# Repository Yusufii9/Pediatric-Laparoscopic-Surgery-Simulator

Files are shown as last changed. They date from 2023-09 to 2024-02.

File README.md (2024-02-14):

# Pediatric Laparoscopic Surgery Simulator

This repository for SYSC4907 Capstone Engineering Project "Pediatric Laparoscopic Surgery Simulator" at Carleton University (Fall 2023/Winter 2024)

## Project Details

- **Authors:** 
1. Atallah Madi
2. Esraa Alaa Aldeen
3. Huda Sheikh
4. Youssef Megahed
- **Date Created:** September 14, 2023
- **Last Edited:** February 14, 2024 

## Description

This project is a simulation software designed for pediatric laparoscopic surgery training. The code simulates various surgical tasks, such as ring and suturing tasks. It captures video input, processes the data, and provides real-time feedback based on sensor data. 

## How to Use

## Reqierments

To run the project, execute the `main.py` file. Different tasks and functionalities can be accessed through the GUI.

## Notes

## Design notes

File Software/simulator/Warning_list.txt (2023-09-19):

Warning Type and times (seconds): 
Force: 
Left Pitch Acceleration: 
Left Yaw Acceleration: 
Right Pitch Acceleration: 
Right Yaw Acceleration: 
Left Surge Acceleration: 
Left Roll Acceleration: 
Right Surge Acceleration: 
Right Roll Acceleration:

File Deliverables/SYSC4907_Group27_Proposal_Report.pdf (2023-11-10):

Capstone Project Proposal

# Pediatric Laparoscopic Surgery Simulator

## Augmented Reality Laparoscopic Surgery Training

Authors:

Atallah Madi | 101156350
Esraa Alaa Aldeen | 101151604
Huda Sheikh | 101144006
Youssef Megahed | 101133061

Group 27

(Biomedical and Electrical Engineering)

Supervised by:

Dr. Carlos Rossa

Report Date:
October 27th, 2023

SYSC 4907

Department of Systems and Computer Engineering

Faculty of Engineering and Design

Carleton University

Project Proposal | Group Number: 27

II

Table of Contents

III

Table of Figures

FIGURE 1 | 2
FIGURE 2 | 2
FIGURE 3 | 3
FIGURE 4 | 3
FIGURE 5 | 19
FIGURE 6 | 19
FIGURE 7 | 23
FIGURE 8 | 27

List of Tables

TABLE 1: | 26
TABLE 2: | 35

### 1. Introduction

This proposal outlines the research and development of the third iteration of the capstone

project that centers on developing a cutting-edge Pediatric Laparoscopic Surgery Simulator,

integrating augmented reality technology and machine learning to enhance its educational utility.

The following sections of this proposal commence with a concise articulation of the project's

primary objective, highlighting the need for innovative training tools in pediatric laparoscopic

surgery. Subsequently, a comprehensive background is constructed, encompassing the essence of

pediatric laparoscopic surgery, extant standards and requisites governing the domain of

laparoscopic surgical training, and a discerning analysis of recent advances in simulation

technology designed to augment the proficiency of laparoscopic surgeons. Furthermore, the

exploration of specific contributions and competencies of each team member, leveraging the

shared discipline of Biomedical and Electrical Engineering, as well as diverse practical

experiences, reinforces the team's collective capability to undertake this complex endeavour.

Moreover, a rigorous exposition of the planned methodologies is presented and supported by a

designed Grantt chart to track the project's milestones and timeline. An extensive risk assessment

and corresponding mitigation strategies are also delineated, followed by a listed inventory of

specialized components indispensable for the project's successful handover.

### 2. Background

Laparoscopic surgery, often called ‘keyhole’ surgery, is a minimally invasive surgical

(MIS) technique that differs from traditional ‘open surgery.’ Instead of making a large incision on

a patient’s abdomen, laparoscopy involves several smaller, 0.5-1 cm diameter incisions, each

called a ‘port’ [1]. A trocar placed inside a hollow sleeve or cannula at each incision or port is

slipped through to create an access point for surgery [2]. A trocar is a pen-shaped instrument

(triangular at one end) placed inside a hollow tubular instrument [2]. An image of a trocar is shown

below in Figure 1.

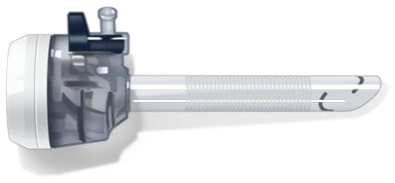
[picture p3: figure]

Figure 1 : Image of a trocar.[2]

In these incisions, the laparoscopic tools, a tube to pump gas into the abdominal cavity,

and a specialized camera called a laparoscope are placed through [3]. A sample placement of these

trocars is shown in Figure 2 below.

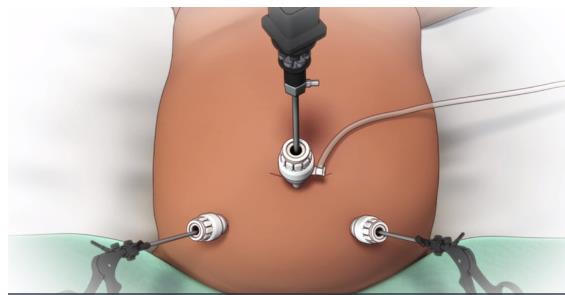
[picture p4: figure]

Figure 2: Pediatric laparoscopic surgery setup with a laparoscope and instruments inserted through trocars [3]

Various laparoscopic instruments available today are made of durable stainless-steel

material with narrow shafts up to 3-5mm diameter to fit through the ports [2]. Along with a

laparoscope, which is a thin telescope equipped with a camera and light source, there are a variety

of other tools available for various functions [2]. Needle drivers, composed of handles, joints, and

jaws, grasp suturing needles while securing wounds and surgical incisions [2]. Their tips may be

curved or straight [2]. Bowel graspers, 3 - 5 mm in diameter, handle and grasp tissue, allowing

surgeons to observe and perform various procedures [2]. Other instruments used in laparoscopy

include scissors, suturing needles, and surgical meshes [2]. An image of these tools is given in

Figure 3 below.

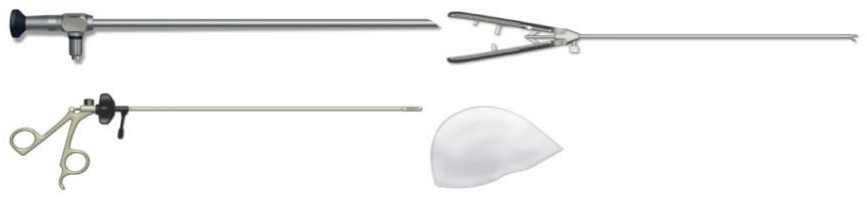
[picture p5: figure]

Figure 3: Laparoscopic instruments commonly used today. From left to right, laparoscope (top left), needle grasper

(top right), bowel grasper (bottom left), and surgical mesh (bottom right) [2]

Additionally, in laparoscopy, surgeons are limited to four degrees of freedom of motion,

which are the yaw, pitch, (counterclockwise/clockwise) roll, and (forward/backward) surge

movements [4]. They lose the heave and sway motions due to the pivots that hold the instruments

in place [4].

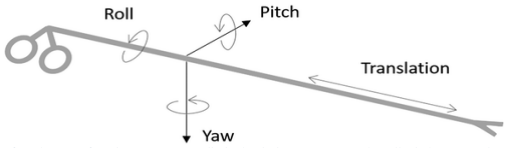
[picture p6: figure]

Figure 4:The four degrees of motion surgeons are limited to in laparoscopy are the roll, pitch, yaw, and surge

(translation) movements [4]

Regarding postoperative outcomes, due to smaller incisions, laparoscopy is associated with

reduced pain post-operation, reduced scarring, reduced hospital stays, and lower incidences of

significant wound complications [5]. That means patients can return to everyday life and engage

in normal activities much sooner after their operation than open-surgery patients [5].

However, laparoscopy is known to have a steeper learning curve for trainees than

conventional open surgery, and each patient-specific procedure can present additional

complications for surgeons and trainees [6]. Thus, training for laparoscopy is different from

conventional open surgery training in several ways. Trainees must work within restricted spaces

and exercise less intuitive and limited movement through the trocars [7]. They must also enhance

their hand-eye coordination capabilities due to the added challenges of operating while looking at

a screen instead of operating under direct vision, like in open surgery [7]. There is also an increased

need to develop manual dexterity skills, like fine motor skills, since the long instruments used in

laparoscopy amplify even small movements and errors made by the trainee [7]. Trainees also

experience the fulcrum effect, which describes the inversion of movement while operating [7]. For

instance, this refers to when the surgeon moves their hand to the right, and the instrument's tooltip

is moved to the patient's left on the screen [7].

Additionally, trainees have to grapple with challenges like only using four out of six

degrees of motion, the lack of physical sensation or touch from their hands, and the lack of 3-

dimensional images like in open surgery [7]. In a clinical setting, laparoscopic training can largely

depend on the variety of cases that arrive at the hospital [6]. Due to the increased need for the

unique skills required for laparoscopy, a need arose to develop relevant simulators and training

programs. Simulators provide trainees with a safe, ethical, and friendly learning environment to develop their hand-eye coordination abilities, improve their manual dexterity, and soften the

learning curve of acquiring laparoscopic skills [6].

When minimally invasive surgery (MIS) was first adapted for infants and children, training

surgeons and residents on pediatric laparoscopy presented additional challenges [8]. The use of

smaller workspaces, shorter and narrower instruments, smaller margins of error, and the expansion

of MIS in children and infants warranted the development of specific learning approaches and

simulators for pediatric laparoscopy [8]. This type of procedure demands a more unique set of

operating skills than adult laparoscopy. The abdomens of children and infants present a small

workspace whereby damage to nearby vessels, the bowel, and other structures can quickly occur

and lead to grave consequences [9]. While the instruments are smaller and narrower, surgeons

must still maneuver these within smaller anatomical structures and a restricted operating field

[9,10]. Due to these limitations, there also exists a lower tolerance of forces to surrounding tissues

[10]. Thus, the demand for the unique skill set to perform the procedure has led to the use and

development of pediatric laparoscopic simulators. These simulators must mimic the challenging

surgical environments in their setup by using smaller instruments, smaller needles, more sensitive

force-sensing devices, and more limited surface areas for training tasks [10].

The Fundamentals of Laparoscopic Surgery (FLS) was a program developed by the Society

of American Gastrointestinal and Endoscopic Surgeons (SAGES) in 2004 to develop a framework

that assesses knowledge and skills acquisition for laparoscopic surgery [11]. The program has been

widely regarded as a valid and reliable tool and educational curriculum to train and assess surgeons

[11]. The Canadian Association of General Surgeons endorses the FLS program as a valuable and

comprehensive training and assessment tool to gauge residents’ knowledge and skills in basic

laparoscopic training. The FLS examination consists of a web-based cognitive examination, followed by a manual-skills assessment on five fundamental laparoscopic tasks, namely, the peg

transfer task, precision cutting task, ligating loop task, suturing with extracorporeal knot-tying

task, and suturing with intracorporeal knot-tying task [11]. For now, and for our group’s proposed

surgical simulator, the focus will be on the peg transfer task and the suturing tasks with

extracorporeal knot-tying and intracorporeal knot-tying [11]. More tasks may be added to our

simulator if time, resources, and efforts allow.

The most straightforward task, the peg transfer task, involves using two Maryland grasper

dissectors [12]. It gets trainees to grasp each ring with their non-dominant hand one by one and

transfer it to their dominant hand in mid-air to place it on a peg on the opposite side of the board

[12]. The process is repeated until all rings are on the other side of the board [12]. This process is

then repeated in reverse, starting with the dominant hand and then transferring the rings to the non-

dominant hand [12]. Penalties are applied if the ring falls out of the field of view or is no longer

retrievable, but trainees are still expected to continue the procedure should this happen [12]. If a

ring is dropped within the field of view, trainees can pick it up with their hands and continue the

procedure [12]. The FLS recommends that trainees complete this entire procedure in 300 seconds,

with the time starting from the minute the grasper touches the first ring till the time the grasper lets

go of the last ring [12].

In the extracorporeal suturing task, trainees are expected to use two needle drivers (or one

Maryland grasper and one needle driver) and endoscopic scissors to place a long suture through

two marks in a Penrose drain and then perform three single throw knots (extracorporeally) to

secure the slit on the drain [12]. Then, once the three throws are secured, both ends of the suture

are cut [12]. Penalties are applied for a knot that falls apart, for deviating from the suturing marks

on the Penrose drain, and for improper closure of the slit [12]. This procedure is expected to be completed within 420 seconds, beginning when the first tool is visible through the camera and

ending when the cuts are made to either end of the suture [12].

Similarly, in the intracorporeal suturing task, trainees are expected to use two needle

drivers (or one Maryland grasper and one needle driver) and endoscopic scissors to place a short

suture through two marks in a Penrose drain and then perform three throws of a knot (one double

throw, and two single throws) intracorporeally to secure the slit on the drain [12]. Then, once the

three throws are secured, both ends of the suture are cut [12]. Penalties are applied for a knot that

falls apart, for deviating from the suturing marks on the Penrose drain, and for improper closure

of the slit [12]. This procedure is expected to be completed within 600 seconds, beginning when

the first tool is visible through the camera and ending when the cuts are made to both ends of the

suture [12]. While a scoring rubric from the FLS is not publicly available, plenty of scoring

methodologies developed by medical professionals exist online. They can be used to assess the

performance of trainees. For instance, many experts have developed independent scoring rubrics

for the five basic laparoscopic tasks [13].

To adapt the FLS training and assessment framework for pediatric laparoscopy, smaller

and softer rings for the peg transfer task, as well as the 3 mm graspers instead of the 5 mm ones

used for adult laparoscopy, should be employed [10]. The size of the Penrose drain used in the

intracorporeal, and extracorporeal suturing tasks should be reduced by 6, and smaller needles and

3 mm instruments should be used [10]. Additionally, the surface area of the Velcro securing the

drain to the board should be decreased by a factor of 5 to increase the risk of avulsion that can

occur due to the application of even minimal force in pediatric laparoscopy [10]. The timing and

penalty scores could be the same as that for adults, except additional parameters or penalties may need to be added to the scoring rubric for pediatric laparoscopies, such as assigning the trainee a

score of zero if avulsion of the Penrose drain occurs [10].

### 2.1. Description of Current Surgical Simulators

The advent of surgical simulators has opened a new avenue in surgical training. It provides

surgical residents and trainees with a safe, trainee-friendly learning environment to practice new

instruments, procedures, and skills before operating on actual patients [1]. Due to the rapidly

changing nature of instruments and laparoscopy’s less intuitive techniques/procedures, it is

difficult to use the traditional apprentice approach when teaching laparoscopic skills to novices

[1]. Thus, many surgical simulators have focused on developing simulation training for

laparoscopic surgery [1]. These have included low-tech and high-tech simulators like video-box

trainers, organic simulators (on human cadavers and animal models), hybrid trainers, virtual reality

(VR) trainers, and augmented reality (AR) simulators [14].

Video-box trainers resemble traditional box trainers in that they provide a box and holes

for trocar insertion and various laparoscopic tasks, but also a camera projected on a monitor for

the trainee [14]. While they can help practice hand-eye coordination skills and particular

laparoscopic tasks, they need more objective expert feedback and focus only on specific

tasks/techniques rather than an entire procedure [14]. They require the presence of an expert to

assess the performance of a trainee, which is only sometimes available. The FLS uses the McGill

Inanimate System for Training and Evaluation of Laparoscopic Skills (MISTELS) system to train

novices on the five core laparoscopic tasks as part of its laparoscopic training program [14].

Hybrid trainers, or virtual reality (VR) trainers, integrate video-box simulators with virtual

reality to guide a trainee throughout a performance with interactive haptic feedback and feedback

metrics without needing an expert surgeon to be present [14]. The user can practice individual skills like suturing, knot-tying, etc. or go through an entire procedure in a realistic computer-

generated environment in more advanced simulators [14]. Objective feedback can be in the form

of time taken for a particular procedure or the strength of a knot [14]. Several VR trainers for

different subspecialties have become available, including LapSim and Lapmentor simulators for

laparoscopy [14]. Sometimes, these simulators may require additional time and effort to set up and

maintain as they are not portable. However, they train residents to make sound decisions, preparing

them for intense operating environments [14].

Finally, augmented reality (AR) trainers, which overlay computer-generated information

into the user’s field of view, connect the virtual world to the real world [14]. Some of the

approaches covered by AR simulators include overlaying computer graphics on anatomical

structures, mapping instrument paths during a procedure, creating a realistic training environment

that involves real instruments interacting with actual artifacts in the surgical environment, and

providing objective force, motion, and haptic feedback without the need of an expert observing

the performance in real-time [14].

The current implementation of our Pediatric Laparoscopic Surgical Simulator project is an

augmented reality (AR) simulator, overlaying the surgical environment in the box trainer with

computer-generated information to guide the user through a laparoscopic task, like the peg transfer

task. Currently, thresholds from sensory information regarding force, velocity, and acceleration of

movement are used to assess trainee performance. Our current focus is to enhance the AR simulator

by adding more advanced laparoscopic tasks and integrating it with powerful machine

learning/data processing algorithms and an interactive user interface to enable it to recognize

surgical gestures and classify a user’s performance based on accurately collected expert data.

### 2.2. Machine Learning and Surgical Simulation

Current literature on laparoscopic surgical simulators has focused on applying artificial

intelligence (AI) to surgical simulators. AI aims to mimic human intelligence by learning to

predict, classify, and learn a particular task to make decisions [15]. AI can enhance surgical

simulators today by assessing a trainee's performance, providing more personalized feedback, and

enhancing the visualization of the surgical environment itself [15]. Among high costs and long-

term maintenance, current VR simulators like LapSim and AR simulators like ProMIS present

other limitations, like insufficient metrics/performance criteria to assess trainees [16]. For instance,

the ProMIS AR laparoscopic simulator uses "time of performance," "path length," and

"smoothness of motion" to assess trainee performance [16].

On the other hand, the LapSim simulator uses "time of performance," "tissue damage," and

"path length" to assess trainee performance [16]. "Time of performance" cannot be the most

important criterion with which to assess trainees, especially since the primary area of concern is

often whether the trainee has used the correct technique and tied a knot properly [16]. Most current

simulators do not accurately assess specific surgical techniques, compare a trainee's performance

to an expert's performance and provide constructive feedback that the user can understand or

implement [17]. Instead, they assume agreed-upon minimum threshold values for completion time,

path length, collisions, force, or velocity to assess a user's performance [17].

Machine learning can evaluate performance more accurately and provide more

personalized feedback to the user. For instance, machine learning algorithms can be trained to

recognize patterns of movement and behaviour in novice and expert performers to provide more

detailed feedback to the user. In this way, incorporating machine learning into our simulator will provide more instructional and informative feedback to the user, increasing the educational value

and usefulness of the simulator itself.

There have been several AI-related applications in surgical simulators in recent years [15].

A group at McGill University developed a machine learning algorithm that classified the skill

levels of surgeons during a brain tumour resection task and provided detailed feedback [15]. This

was done by getting machine learning algorithms to select important performance metrics from an

expert-defined list and use these to distinguish between the skill levels of surgeons in a virtual

reality simulator [15]. The algorithms could select a novel list of performance metrics and achieve

high classification accuracies when classifying trainee performances along training levels [15].

However, the challenges and problems introduced by applying AI and machine learning to surgical

simulation training must be addressed. For one, the lack of valid and objective performance metrics

for an algorithm to use, and another, the inability of the algorithm to accurately correlate between

a trainee's performance on a simulator and in the operating room [15]. In addition, these algorithms

may not consider the variety of methods and techniques trainees can use to achieve a particular

goal. Potential solutions to these problems could be to divide a procedure into sub-tasks and obtain

surgeon-led consensus on evaluation metrics in laparoscopy.

We aim to integrate our current AR pediatric laparoscopic surgical simulator with machine

learning algorithms to 1) classify individual gestures or sub-tasks within a surgical procedure (like

the peg transfer and suturing tasks) and 2) evaluate a trainee's performance and compare them to

an expert's performance. Our conversation with pediatric surgeons Dr. Ahmed Nasr and Dr.

Georges Azzie on September 27th, 2023, focused on how the machine learning algorithms that we

will develop can assess a trainee's success in completing each sub-task of a procedure by evaluating

their smoothness of movement, patterns of motion, and application of force. Each trainee's performance will be compared against the performances of actual, standard, expert data we have

collected. Our methodology regarding our machine learning approach is explained in Section 6,

our Methodology section.

### 3. Project Objective

The last iteration of the project focused on implementing a functioning box simulator

equipped with proper sensors to measure the characteristics of a surgeon’s hand movement and

force. The simulator was interfaced with augmented reality to provide simple but overly

mathematical feedback to the user through warnings and detailed graphs.

The primary goal of this capstone project is to develop a user-friendly training device for

pediatric laparoscopic surgery, integrating an embedded system for real-time guidance and

feedback. This iteration aims to reduce the reliance on expert surgical mentors, providing trainees

with a versatile and safe platform to improve their surgical skills independently while comparing

their performance to professional surgeons. Specific, measurable, functional, and non-functional

criteria will be employed to measure progress effectively. Functionally, the device's sensors must

accurately track intricate hand movements and measure applied forces on the training platform.

This multifaceted sensor system will facilitate real-time feedback through an augmented reality

interface to enhance the trainee's learning experience. However, the non-functional criteria will

cover factors related to the system's back and front end. The backend evaluates data pipelines,

signal processing, and machine learning model validation. The front end assesses the system

interface's responsiveness and robustness in delivering consistent feedback, including labelled

videos highlighting areas for improvement. A significant project objective is to enhance the

existing training setup by integrating new hardware components and then building efficient data

pipelines to process data from these integrated sensors and feed it to machine learning models.

Lastly, the project's final milestone includes presenting this data through augmented reality to

convey critical information and compare the trainee's performance to benchmarks supported by

machine learning models. This project signifies a commitment to advancing pediatric laparoscopic surgical training by combining technological innovation and education, creating a transformative

tool with significant potential to enhance surgical skills among trainees.

The design of this project will be executed in consultation with our supervisor, Dr. Carlos

Rossa, as well as pediatric surgeons from CHEO and the SickKids Hospital in Toronto, Dr. Ahmed

Nasr, and Dr. Georges Azzie.

### 4. Relevance to Degree Program

All members of the team - Atallah, Esraa, Huda, and Youssef - are currently in their final

year of their undergraduate degree program in Biomedical and Electrical Engineering. The degree

has equipped us with a shared foundational knowledge and skill set essential for our collaborative

effort. While each member brings unique strengths and expertise to the project, we all share a solid

academic background, ensuring that our overall project contributions will be closely aligned with

our studies and objectives.

Atallah’s academic journey has given him a deep understanding of concepts such as project

design, biomedical instrumentation, digital and analog electrical circuits, and various

programming languages. All these fundamental concepts come together to build his pivotal role in

the project, where he will focus on enhancing the platform design, upgrading its instrumentation,

and building the system data pipelines. His hardware, software, and electrical academic

background equip him with the skills essential to the project.

Esraa will utilize her academic knowledge to give her the essential skills and ability to

effectively contribute to gesture recognition of laparoscopic tasks. Her task will be accomplished

using deep learning or deep convolutional networks, which will extract robust features from real-

time data, and help provide several kinds of guidance according to the object states in training, to

enable easily understandable real-time feedback.

Huda, throughout her degree, alongside her course work, has worked on several projects

related to biomedical engineering in academics, research, and industry. Throughout these projects,

she has gained experience in image processing, biomedical imaging, sensor analysis, software

development, and project management. Huda’s primary role in this project will consist of

consolidating the machine learning aspects of the project (the performance assessment and gesture classification algorithms) with a powerful, interactive user interface (UI) that will guide and assess

a trainee throughout their performance. She will also ensure that the laparoscopic tasks added to

the project, such as the ring transfer and extracorporeal and intracorporeal suturing tasks, align

with the Fundamentals of Laparoscopic Surgery (FLS) requirements. This will ensure that the

laparoscopic surgical simulator functions correctly to give the user interactive feedback, as the

performance assessment and gesture classification algorithms provide.

Youssef's degree has afforded him comprehensive exposure to hardware/software

development, electrical engineering, and the intricacies of biomedical engineering. Beyond his

academic studies, Youssef has garnered hands-on experience in medical imaging research,

harnessing the power of deep learning. He has also honed his skills as a data science intern, adeptly

utilizing machine learning and Python. Youssef's combined expertise will be beneficial as he

works on developing the laparoscopic training simulator. His primary focus will be signal

processing and utilizing machine learning for classification purposes. Leveraging his deep-rooted

knowledge in biomedical engineering and data science, Youssef is poised to develop a robust

signal classification algorithm. This algorithm will adeptly process simulation data to assess

trainee performance accurately. Regarding signal processing, Youssef will adequately cleanse and

standardize raw sensor data, structuring it into data frames and saving them as CSV files. This

streamlined data will then be fed into the classification algorithm, offering insightful evaluations

of trainee performance. Youssef's diverse techniques and methodologies during his studies and

work serve as the foundation for his approach, promising users of the training simulator clarity

and precision in results.

### 5. Skills and Expertise

Our project is structured around four primary aspects: hardware development

improvements, signal processing and classification, gesture recognition, and user interface (UI)

enhancements. Drawing upon the engineering and design skills we have cultivated at Carleton

University, complemented by our co-op work experiences, our team is poised to execute these

tasks proficiently.

As a Digital Hardware Co-op with deep expertise in embedded systems, Atallah's

background plays a critical role in integrating new sensors. His skills in interfacing sensors with

microcontrollers ensure precise data collection. As an Undergraduate Research Assistant, he

excelled in optimizing data pipelines for complex CNN models in medical imaging. Atallah's skill

in constructing efficient data pipelines, refined through academic and professional experiences, is

vital for effectively managing data flow and processing. His proficiency in sensor integration,

platform instrumentation, and data pipeline optimization is pivotal for hardware improvements

with precision and excellence.

Esraa will leverage her grounding in biomedical and electrical engineering to harness the

power of deep learning. Her role involves extracting pivotal features from real-time data, a crucial

step toward achieving accurate gesture recognition. Gesture recognition will undoubtedly boost

the simulator's training efficacy.

Huda will combine her biomedical, electrical engineering, and software development

knowledge to create an interactive user interface (UI). Her vision also encompasses integrating

advanced laparoscopic tasks, such as the extracorporeal and intracorporeal suturing tasks, into the

simulator's existing setup.

With his biomedical and electrical engineering studies and a robust background in data

science and software development, Youssef will be responsible for signal processing. He will

further utilize Machine Learning algorithms for signal classification, aiming to enhance the trainee

experience by providing constructive feedback that can serve as a blueprint for performance

improvement.

With this diverse skill set, our team can handle individual responsibilities and provide

collaborative support when required. We are confident in our ability to deliver on the project's

expectations.

### 6. Methodology

### 6.1. Hardware Improvements

After conducting comprehensive testing and validating the project setup from the second

iteration, several key issues were identified within the overall design. These issues included

stability concerns, inaccuracies in readings, and inadequate housing for the sensors. Therefore, this

iteration's primary objective is to address these concerns by redesigning the current platform and

incorporating additional force sensors.

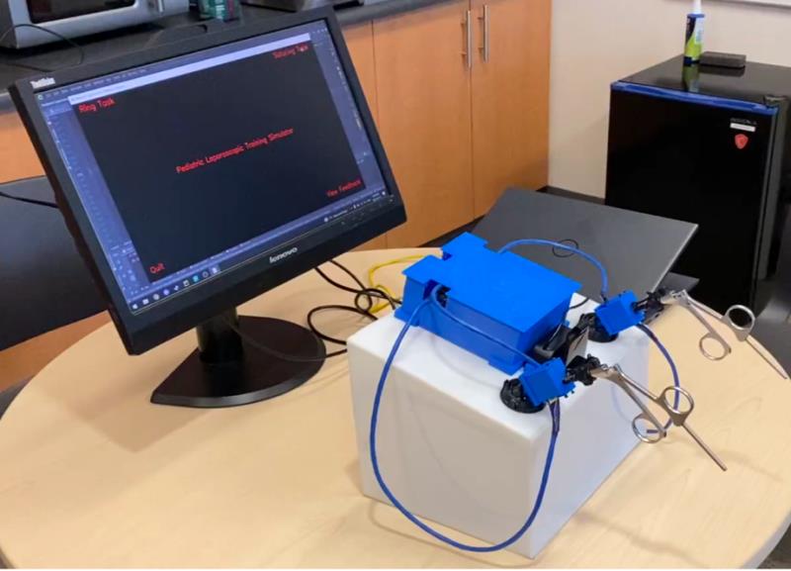
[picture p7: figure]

Figure 5: Current setup for the laparoscopic surgery trainer.

### 6.1.1. Force Sensors and Platform Redesign

For the force sensors, the current design allows the system to measure only the downward

applied force by placing FC22-31 0000 0100-L at the bottom of the platform, as shown in Figure

6.

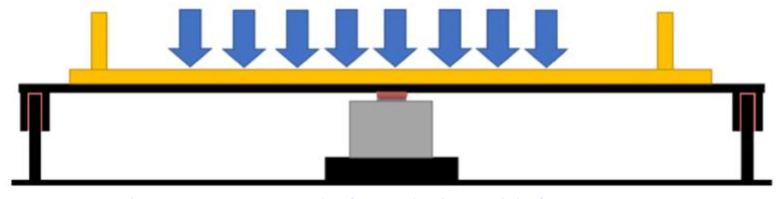
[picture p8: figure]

Figure 6: Current platform design with force sensor.

The sensor has a wide range of 0 to 100 ft-lb of force that can be detected [18]. The sensor

output is amplified by AD620 operational amplifiers to have an output ranging from 0 – 5V,

providing a higher resolution when converting the signal from analog to digital. A second force

sensor will be placed to improve the current accuracy of the downward force by averaging two

readings. Furthermore, two sensors will be added with an inverted configuration to collect upward

forces. This will highlight the forces applied in both directions, which in real-world applications

could damage and tear the patient’s tissues in surgery.

To strengthen platform stability, a comprehensive redesign has been undertaken using

Fusion 360 Computer-Aided Design (CAD) software. This redesign employs advanced CAD

techniques to refine the platform's structural integrity. The primary objective of this redesign is to

eliminate platform instability and reduce dependency on adhesives for stabilizing different

procedural platforms, which may cause damage when they are swapped. Additionally, within this

redesign, new space will be allocated for integrating new force sensors, improving the platform's

capacity to gather precise data and overall performance.

### 6.1.2. Embedded System

The existing microcontroller, Arduino Mega 2560 Rev 3, has been replaced with an

Arduino Nano Rev 3. This strategic transition was motivated by the imperative to maintain the

existing level of functionality while concurrently achieving a substantial reduction in the physical

footprint occupied by the microcontroller. This space will be occupied by a mounted screen and a

compact computer to achieve a truly portable design. The data pipelines are essential for feeding

data to the computer where the Python application runs to incorporate augmented reality

experiences. Therefore, fast serial communication between the microcontroller and the computer is much needed. This can be achieved using a fast serial communication protocol such as I2C

between the ends [19].

Clear and concise schematics are needed for a seamless hardware upgrade of the system.

This requirement can be met by using KiCad software to develop new schematics and incorporate

new components like force sensors and operational amplifiers. This simplifies the process and

makes building and working with intricate circuitry easier while maintaining the system's

functionality within spatial constraints.

### 6.2. Signal Processing and Classification

### 6.2.1. Sensor Data Collection and Initial Processing

During our simulator's most recent iteration, real-time data collected during simulations is

handled by an Arduino microcontroller on our end. The fundamental nature of the Arduino makes

it possible to acquire data from each sensor via the use of a signal controller in a seamless manner.

Therefore, this produces a complete dataset that includes parameters such as rotation, position,

speed, acceleration, and force. More classification is required to differentiate between the many

measures each metric represents.

Text files are used to store the raw data that is collected from the various sensors. Thus, a

Python script was developed that uses the 'tkinter' library so that the data processing can be done

more quickly. This script displays a dialogue window, which allows users to pick the appropriate

text file containing sensor data. After the selection, the data is cleaned, organized into a DataFrame,

and saved as a CSV file using the 'pandas' library. The visualization of data and its preparation for

classification algorithms may benefit from this automation's acceleration.

### 6.2.2. Enhancing Training Experience through Machine Learning

A pivotal aspect of this project is enhancing the trainee experience. In order to achieve this

goal, we are in the process of developing a machine-learning classification model. This model will

categorize trainee-generated signals into one of three proficiency levels: "Novice," "Intermediate,"

or "Expert." The classification is achieved by comparing the trainee's signal against a benchmark

'expert' signal, which is the model's training data.

Considering the input provided by the surgeons, we are emphasizing our feedback

mechanism. One strategy entails segmenting each task into smaller and more specific subtasks,

providing trainees with detailed insights into areas of improvement. For instance, the 'ring transfer'

task can be broken down into five distinct subtasks:

1. Retrieving the ring from the initial peg.
2. Maneuvering the ring to the task area's center.
3. Transferring the peg between graspers.
4. Relocating the ring to the designated peg.
5. Securing the ring onto the destination peg.

Given this segmentation, adopting a standardization approach from the 'sklearn' library is

imperative, ensuring uniformity in data points for each subtask across all trainees.

### 6.2.3. Dynamic Time Warping for Segment Matching

We will employ the Dynamic Time Warping (DTW) algorithm, available through the

'fastdtw' library, to identify and extract segments from trainee signals that align with expert signal

segments. The 'euclidean' distance metric from the 'scipy' library facilitates this comparison. DTW

stands out as a time-series similarity measure, adept at countering the effects of temporal shifts and distortions. It achieves this by enabling elastic adjustments to time series, ensuring the

detection of congruent shapes even if they manifest in differing phases [20].

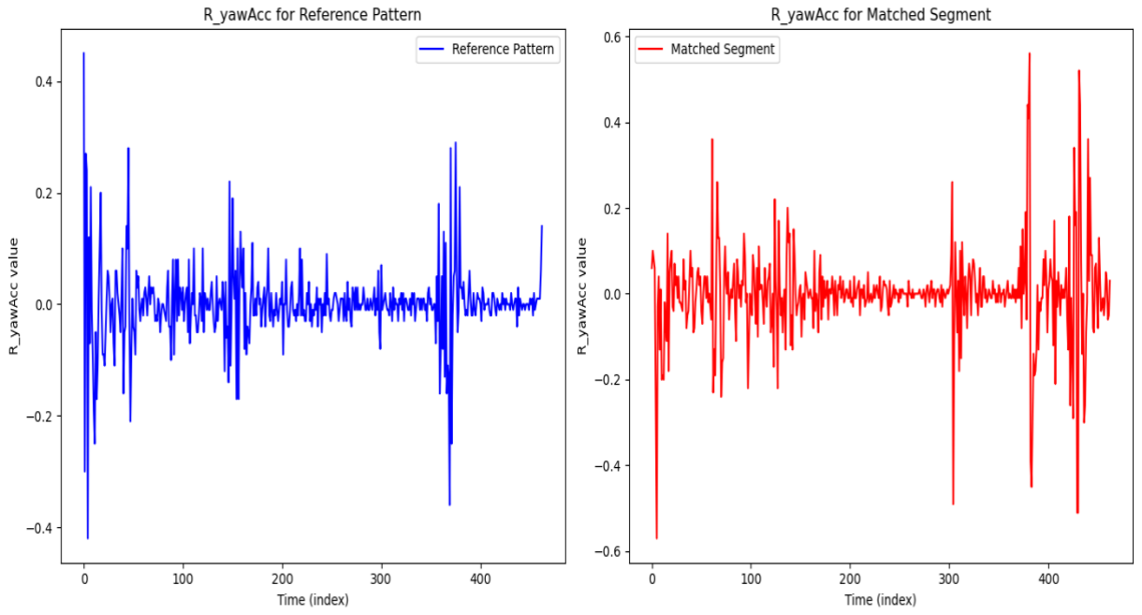
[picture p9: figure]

Figure 7: Comparative Analysis of ‘R_yawAcc’ signals: Reference Pattern vs. Matched Segment using DTW.

DTW's unique approach to time series comparison is essential in the context of our project.

It guarantees that trainee movements are recognized and evaluated accurately, as Figure 7 shows,

even if they are somewhat out of rhythm with expert maneuvers, delivering a fair and meaningful

assessment. By combining these aspects, the classification algorithm promises to be a robust tool

capable of providing informative feedback on trainees' performance and areas for potential

improvement.

### 6.3. Object Recognition

Many surgery complications are caused by inadequate individual team performance, for

which poor training and feedback play an essential role [21]. However, research indicates that half

of the adverse surgical circumstances are preventable. One improvement could be objective feedback through an object detection approach providing real-time automated surgical video

analysis. Hence, it is a way to evaluate the trainee's skills objectively and efficiently.

Deep learning-based approaches have two types: one-stage detectors and two-stage

detectors. In two-stage detectors, using deep features, the object detection method is applied to

locate and detect the developed semantic objects in an image [22]. Then, these components are

used for the classification and bounding box regression for the object candidate. Also, it will

achieve high detection accuracy [22].

On the other hand, bounding boxes are predicted over the images in one-stage detectors

without the region proposal step [22]. This process does not consume time and can be used in real-

time devices. Hence, for our design, our model's performance will rely on the object recognition

capability of the selected detection method and implementations of the different state-of-the-art

techniques that propose several efficient solutions and new directions as the plans to provide an

overview of how other deep learning models are used in generic object detection, specific object

detection, and object tracking [22].

Therefore, this task has two objectives: 1) The object modelling for the training task and

2) Object detection using deep learning to support real-time application of the simulator.

### 6.3.1. Object Modelling

Object modelling in machine learning refers to characterizing and describing objects to

allow machine learning algorithms to understand and work with them. Object modelling involves

determining a structured representation of objects, usually as attributes. The main objects for this

task are the left grasper, right grasper, and the ring states. The object model contains two

fundamental attributes for each target object:

- Location: to determine the exact pixel coordinates for the grasper.

- Movement: Our design considers movement a relationship between the objects and any

other object, such as holding the ring together with the left grasper, that indicates a

movement of “Ring transfer.”

Thus, each target object may have several object movements, as shown in Table 1, and

objects such as the ring and the grasper are required to know their movement. However, when

objects are represented in semantic modelling along with their semantic attributes and

relationships, machines can understand their meaning [23]

The semantic object model offers a method of representing objects in a task by combining

movement and object type attributes into a single attribute: location. The advantage of this

semantic object technique is the simplification of object state detection, as it will only detect the

location of the objects. This simplification can direct to efficient object detection methods.

Table 1: The Objects Classification by Movement and Location.

Gesture Index

(R: Right) and (L:

Left)

Objects Movement

Jaws (Open

or Closed)

RG0 | Ring on peg: Idle state (or hovering) | C
RG1 | Right grasper: Moving vertically downwards towards peg on right side of operating table | O/C
RG2 | Ring out peg: Positioning ring between the jaws and clasping it | O
RG3 | Right pick ring: Moving upwards with clasped ring | O
RG4 | Right Carry ring: Moving to center of operating table to meet left grasper | O
RG5 | Right carry ring: Hovering with ring between jaws for left grasper to pick | O
RG6 | Ring transfer: Holding ring together with left grasper | O
RG7 | Right pick ring: Opening jaws to let go of ring | O
RG8 | Moving aside | O/C
LG0 | Idle state (or hovering) | C
LG1 | Left grasper: Moving to center of operating table to meet right grasper | O/C
LG2 | Left pick ring: Positioning ring between the jaws | O
LG3 | Left pick ring: Clasping ring | O
LG4 | Left carry ring: Moving horizontally (straight or diagonally) towards a peg on left side of operating table | O
LG5 | Left carry ring: Positioning ring over peg | O
LG6 | Ring on peg: Opening jaws and dropping ring through peg | O/C
LG7 | Ring on peg: Moving aside after transferring all three rings | O/C

### 6.3.2. Object detection using deep learning: Single Shot Detection

A single-shot detector is a one-phase detector that predicts multiple classes. In other words,

a real-time object detection framework that merges the tasks of object localization and type into a

single unified architecture [24]. In this task, after modelling the semantic objects. The primary plan

concept is Multiscale Bounding Box Prediction and the training.

### 6.3.2.1. Multiscale Bounding Box Prediction

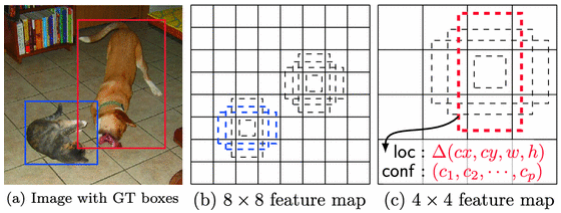
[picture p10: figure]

Figure 8: The figure shows SSD framework (a) Image with GT box. (b) 8×8 feature map. (c) 4×4 feature map.[24]

The SSD approach's target output is to predict an object's presence on different scales. This

multiscale technique allows SSD to detect objects of various dimensions and positions in the input

image. The approach is as follows:

- Input Image and Ground Truth: The SSD only needs an input image with objects to be

detected. The object in the image is associated with a ground truth box for each object

during training, as shown in Figure 8 (a) [24].

- Convolutional Neural Network (CNN): using CNN to detect objects of different sizes and

forms, these boxes are considered at multiple positions on different feature maps of various

resolutions (as shown in Figures 8 b and c: 8x8 and 4x4).

- Multiple Fixed Scale Grid Feature Maps: generates multiple fixed-scale grid feature maps

and captures segments at various spatial resolutions within the image shown in Figure 8(b)

and (c).

- Default Boxes: A collection of default boxes is connected per location on the feature maps

and operates as reference templates for object detection.

- Multiscale Bounding Box Prediction: aims to predict objects' existence at multiple scales.
- Final Feature Map: All the feature maps from other scales are compiled into a final feature

map containing the predictions for shape offsets, classification scores and attributes for

each default box.

### 6.3.2.2. Training

Dataset Preparation: A training dataset is prepared that contains labelled images. Each

image should have ground truth information that needs to be assigned to specific outputs in the

fixed set of detector outputs [24].

- The loss function and backpropagation: The loss function generally has object localization

and classification components. Represent a loss function quantifying the discrepancy

between the model's predictions and the ground truth information.

- Default Box Selection
- Ground Truth Label Conversion: The ground truth information for the training images is

converted to correspond to the output format expected by the SSD model.

- Dataset Augmentation: Each training image is randomly sampled to construct a better and

more robust model with different input object dimensions and shapes [24].

- Training Iterations: In each iteration, the model processes small batches of images and

updates its parameters using a matching optimization algorithm.

- Validation and Thresholding: A threshold is used to select which object detections are

proper based on confidence scores. Detections with scores beyond the threshold are

retained.

### 6.4. User Interface Design

The design of the user interface will be implemented using Python’s tkinter package, which

is a standard interface for a GUI toolkit [25]. This package provides an efficient way for us to

implement buttons, display screens, menus, and images that will guide the trainee throughout the

execution of their training program. This user interface will be implemented through object-

oriented programming, a programming paradigm that defines classes of independent objects with

inherited methods and variables but their states [26]. This will allow for code reusability,

efficiency, and extensibility and is usually the default programming paradigm for a program of

this type and scale.

### 6.5. Laparoscopic Training Tasks

This project will implement the peg transfer task and the intracorporeal and extracorporeal

tasks from the FLS program. While the current implementation of the peg transfer task is set up

with three pegs on either side of the board and three rings to transfer, the suturing task has yet to

be formally set up in the previous implementation of this project. A durable silicone suturing pad

will be sealed to the platform of the box simulator. Materials needed for the suturing task will be

2/0, 3/0 or 4/0 curved suturing needles of the longest available size, like 25 mm or 17 mm needles

(for ease of visibility through a camera), as well as two needle drivers, and one pair of endoscopic

scissors to perform the task.

### 7. Project Timetable

A Gantt chart is a project management tool visually representing a project's timeline and

objectives. It displays tasks on the vertical axis and time on the horizontal axis, enabling team

members to visualize the project's progression and discern the interrelation between various

subtasks.

Every member has described their responsibilities for the 2023-2024 year and estimated

the duration required to complete their tasks. Also, we have set collaborative milestones, such as

the final project deliverable, based on contributions from all the team members. Everyone must

dedicate at least 8 hours weekly to the project throughout the year. The Gantt chart detailing this

can be found attached in Appendix A.

### 8. Risk Assessment and Mitigation

Considering potential risks and developing mitigation plans is crucial for effective project

management. This approach helps the project team to be prepared for uncertainties and enhances

the possibilities of project success. Identifying potential issues that could occur during the project

is a crucial initial step, such as the change from the Arduino Mega 2560 Rev 3 to the Arduino

Nano Rev 3. This change carries potential risks, specifically regarding software compatibility and

unexpected hardware adaptation challenges. However, a well-defined plan has been set to manage

these circumstances, including comprehensive testing and validation procedures to ensure a

smooth transition, thereby reducing the risk of functional disruptions. Other team members have

also implemented and thoroughly reviewed a detailed schematic model to minimize errors and

ensure the seamless integration of new components. These measures are created to mitigate

potential risks to the project timeline and ensure these critical hardware advancements are

successfully implemented.

Instability during the training box platform assessment was observed and identified several

risks. A platform redesign using Fusion 360 (CAD) software was proposed to address this issue.

However, due to potential design compatibility problems, new structural changes and force sensors

could result in unexpected issues. To mitigate these risks, the supervisor will conduct design

reviews and implement trial-and-error plans to ensure the seamless integration and compatibility

of the changes.

Furthermore, storing project information and data is essential to ensure the project's

continuity and success. We use cloud services, such as OneDrive for files and documentation,

GitHub for software, and Fusion 360 for design backups, to mitigate the risk of data or information

loss. However, despite the reliability of these cloud services, there is always a potential risk of data loss. To address this, we will schedule regular backups to ensure redundant storage across multiple

locations. Also, automated backup and version control systems will be implemented to minimize

the risk of data loss.

### 9. Special Components and Facilities

As we begin the third iteration of our project, we will use a wide range of specialized tools

and components.

1. 3D Modeling & Printing:
- Modelling Software: We will utilize AutoDesk Fusion 360 for 3D modeling.
- 3D Printer: The DREMEL from Digilab, located in the Biomechatronic lab, will print our

designs.

- PLA Filament: Used for 3D printing components, it emulates the physical environment of

a pediatric abdomen during laparoscopy.

2. Sensor Communication & Control
- Microcontroller: The Arduino Nano Rev 3 will interface with the PMW 3389, MPU 6050,

and FC2211-0000-0025-L sensors

- Development Environment: The open-source Arduino IDE ensures seamless sensor

communication.

3. Software Development & Data Processing
- Python Language: A versatile choice for augmented reality, signal processing,

classification algorithms, and gesture recognition. It is also compatible with the Arduino

Nano Rev 3 for serial data communication and supports machine and deep learning

applications.

4. Simulator Design & Components
- AutoCAD: Precision design software for crafting the platform housing diverse laparoscopy

tasks.

- Force Sensors (FC2211-0000-0025-L): Vital for tactile feedback simulation during

laparoscopic procedures, aiding trainees in honing their touch and dexterity.

- Operational Amplifiers (AD620): Four amplifiers will condition and amplify signals from

the force sensors.

- Suturing Equipment: A suturing pad and 26mm needles enable realistic suturing technique

practice.

- PWM 3389 and MPU-6050: Essential for the four degrees of movements
5. Components depend on the approval of additional funding.
- Mini PC: This acts as the simulator's computing heart, orchestrating software simulations,

performance metric recording, and trainee feedback.

- LED Matrix: The matrix gives a realistic representation of the surgical field, while the

wires cater to circuitry needs.

- Display & Feedback System: An IPS display, and FOV web camera collectively create an

immersive training interface.

With this comprehensive suite, we are poised to deliver a simulator that offers trainees a holistic,

realistic, and educative experience.

### 10. Report Contributions

Table 2: Outline of each member's contribution to the proposal report

Contributor | Section
Atallah Madi | • Introduction • Project Objective • Relevance to Degree Program • Methodology (Hardware Improvements)
Esraa Alaa Aldeen | • Relevance to Degree Program • Methodology (Object Recognition) • Project Timetable • Risk Assessment and Mitigation
Huda Sheikh | • Background • Relevance to Degree Program • Methodology (User Interface and Design Laparoscopic Training Tasks)
Youssef Megahed | • Relevance to Degree Program • Skills and Expertise • Methodology (Signal Processing and Classification) • Special Components and Facilities

References

[1] “Laparoscopic Surgery - What is it? | ASCRS,” fascrs.org.

https://fascrs.org/patients/diseases-and-conditions/a-z/laparoscopic-surgery-what-is-it

[2] “What Tools are Used in Laparoscopic Surgery | Laparoscopic.MD,”

https://www.laparoscopic.md/surgery/instruments#:~:text=Laparoscopic%20instruments

%20are%20made%20of (accessed Oct. 14, 2023).

[3] “Laparoscopy in Children,” myhealth.alberta.ca.

https://myhealth.alberta.ca/health/Pages/conditions.aspx?hwid=acg9455 (accessed Oct.

14, 2023).

[4] Bojan Gavrilović, A. S. Fahy, B. Carrillo, A. Nasr, J. Ted Gerstle, and Georges Azzie,

“Development of an Open-Source Laparoscopic Simulator Capable of Motion and Force

Assessment: High Tech at Low Cost,” Journal of Laparoendoscopic & Advanced

Surgical Techniques, vol. 28, no. 10, pp. 1253–1260, Oct. 2018, doi:

https://doi.org/10.1089/lap.2018.0126.

[5] P. K. H. Tam, “Current topic: Laparoscopic surgery in children,” Archives of Disease in

Childhood, vol. 82, no. 3, pp. 240–243, Mar. 2000, doi:

https://doi.org/10.1136/adc.82.3.240.

[6] E. Westwood, B. Malla, J. Ward, R. Lal, and K. Aryal, “The Impact of a Laparoscopic

Surgery Training Course in a Developing Country,” World Journal of Surgery, vol. 44,

no. 10, pp. 3284–3289, Jun. 2020, doi: https://doi.org/10.1007/s00268-020-05606-y.

[7] M. Nagendran, C. D. Toon, B. R. Davidson, and K. S. Gurusamy, “Laparoscopic surgical box

model training for surgical trainees with no prior laparoscopic experience,” Cochrane

Database of Systematic Reviews, Jan. 2014, doi:

https://doi.org/10.1002/14651858.cd010479.pub2.

[8] Y. A. Oquendo, E. W. Riddle, D. Hiller, T. A. Blinman, and K. J. Kuchenbecker,

“Automatically rating trainee skill at a pediatric laparoscopic suturing task,” Surgical

Endoscopy, vol. 32, no. 4, pp. 1840–1857, Oct. 2017, doi:

https://doi.org/10.1007/s00464-017-5873-6.

[9] P. Korzeniowski, C. S. Chacon, V. R. Russell, S. A. Clarke, and F. Bello, “Virtual Reality

Simulator for Pediatric Laparoscopic Inguinal Hernia Repair,” Journal of

Laparoendoscopic & Advanced Surgical Techniques, vol. 31, no. 11, pp. 1322–1330,

Nov. 2021, doi: https://doi.org/10.1089/lap.2020.0423.

[10] G. Azzie et al., “Development and validation of a pediatric laparoscopic surgery simulator,”

Journal of Pediatric Surgery, vol. 46, no. 5, pp. 897–903, May 2011, doi:

https://doi.org/10.1016/j.jpedsurg.2011.02.026.

[11] H.-C. Hur, D. Arden, L. E. Dodge, B. Zheng, and H. A. Ricciotti, “Fundamentals of

Laparoscopic Surgery: A Surgical Skills Assessment Tool in Gynecology,” vol. 15, no. 1,

pp. 21–26, Jan. 2011, doi: https://doi.org/10.4293/108680810x12924466009122.

[12] “FLS Manual Skills Written Instructions and Performance Guidelines Important Scoring

Information.” Accessed: Aug. 26, 2022. [Online]. Available:

https://www.flsprogram.org/wp-content/uploads/2014/03/Revised-Manual-Skills-

Guidelines-February-2014.pdf

[13] S. Miles and N. Donnellan, “Learning Fundamentals of Laparoscopic Surgery Manual

Skills: An Institutional Experience With Remote Coaching and Assessment,” Military

Medicine, Apr. 2021, doi: https://doi.org/10.1093/milmed/usab170.

[14] M. Varras, N. Nikiteas, V. Varra, F. Varra, E. Georgiou, and C. Loukas, “Role of

laparoscopic simulators in the development and assessment of laparoscopic surgical skills

in laparoscopic surgery and gynecology (Review),” World Academy of Sciences Journal,

Mar. 2020, doi: https://doi.org/10.3892/wasj.2020.41.

[15] J. J. Park, J. Tiefenbach, and A. K. Demetriades, “The role of artificial intelligence in

surgical simulation,” vol. 4, Dec. 2022, doi: https://doi.org/10.3389/fmedt.2022.1076755.

[16] S. M. B. I. Botden, S. N. Buzink, M. P. Schijven, and J. J. Jakimowicz, “Augmented versus

Virtual Reality Laparoscopic Simulation: What Is the Difference?,” World Journal of

Surgery, vol. 31, no. 4, pp. 764–772, Mar. 2007, doi: https://doi.org/10.1007/s00268-006-

0724-y.

[17] C. Sewell et al., “Providing metrics and performance feedback in a surgical simulator,”

Computer Aided Surgery, vol. 13, no. 2, pp. 63–81, Jan. 2008, doi:

https://doi.org/10.3109/10929080801957712.

[18] “Compression Load Cell - 100mV / 0.5-4.5V | FC22 Series,” Compression Load Cell -
100mV / 0.5-4.5V | FC22 Series. https://www.te.com/usa-en/product-CAT-FSE0001.html

(accessed Oct. 18, 2023).

[19] Arduino, “Arduino Nano,” Arduino Official Store. https://store.arduino.cc/products/arduino-

nano

[20] P. Senin, “Dynamic time warping algorithm review.” Information and Computer Science

Department University of Hawaii at Manoa Honolulu, USA, 855(1-23), 40, December

2008. [Accessed Oct. 7, 2023]. Available: https://www.researchgate.net/profile/Pavel-

Senin/publication/228785661_Dynamic_Time_Warping_Algorithm_Review/links/02bfe

5100f11a7929f000000/Dynamic-Time-Warping-Algorithm-Review.pdf.

[21] Gawande AA, Thomas EJ, Zinner MJ, Brennan TA. The incidence and nature of surgical

adverse events in Colorado and Utah in 1992. Surgery. 1999 Jul;126(1):66-75. doi:

10.1067/msy.1999.98664. PMID: 10418594.

[22] Pal, S.K., Pramanik, A., Maiti, J. et al. Deep learning in multi-object detection and tracking:

state of the art. Appl Intell 51, 6400–6429 (2021). https://doi.org/10.1007/s10489-021-

02293-7

[23] Brachman, R. J., & Levesque, H. J. (2009). Knowledge representation and reasoning.

Elsevier.

[24] Liu, W. et al. (2016). SSD: Single Shot MultiBox Detector. In: Leibe, B., Matas, J., Sebe,

N., Welling, M. (eds) Computer Vision – ECCV 2016. ECCV 2016. Lecture Notes in

Computer Science (), vol 9905. Springer, Cham. https://doi.org/10.1007/978-3-319-

46448-0_2

[25] Python Software Foundation, “tkinter — Python interface to Tcl/Tk — Python 3.7.2

documentation,” python.org, 2019. https://docs.python.org/3/library/tkinter.html

[26] Major programming paradigms,” www.cs.ucf.edu.

https://www.cs.ucf.edu/~leavens/ComS541Fall97/hw-

pages/paradigms/major.html#functional (accessed Oct. 14, 2023).

Appendix A (Grantt Chart)

Project Deliverables | Group Milestones | Esraa | Youssef | Huda | Atallah

Task

15-Oct | 30-Oct | 06-Nov | 13-Nov | 20-Nov | 27-Nov | 04-Dec | 08-Dec | 18-Dec | 08-Jan | 15-Jan | 22-Jan | 29-Jan | 05-Feb | 12-Feb | 19-Feb | 26-Feb | 05-Mar | 14-Mar | 19-Mar | 26-Mar | 02-Apr | 10-Apr | END

Project Deliverables
Progress Report
Oral Presentation
Poster Fair
Demo Video
Final Report

CreateNew Project Schematic
Design new platform
ConfigureArduino Nano
Have functioning simulator with processed output
Test the functionality ofthe simulator
Pereparenew hardware added by the adddiational funding

Script to Clean/Organize Sensor Data
Editing theMain Code to SaveMultipleUser Runs
Gathering MoreUser Data
ImplementingDTW to Segment User Signals
Processthe Segmented User Signal to Comparewith Expert Data Validating theModel
Improvementsto the Existing Model
Displaying the Feedback to theUser
Object Recognition
Collect multiple videos demonstrating each gesture Gather a dataset with labeled images Pre-processtheData
Train theModel
Implement Real-TimeGestureRecognition AutomateData Entry in Excel
Run themodel on the validation set Improvements
User-InerfaceDevelopment
Design user interface (UI) prototype Implementstarting screen for UI
Implement code and button flow for UI
Refactor existing code into UI usingOOP
EvaluateUI, conduct testing with hardware, and add improvements Finalize theUI and ensure itsfunctionality with simulator
Implementing Laproscopic Tasks
Purchase suturing equipment
Practice extracorporeal suturing with suturing pad and laparoscopic tools Practice intracorporeal suturing with suturing pad and laparoscopic tools Implementsuturing tasksin simulator
Use suturing tasksin sensor analysis, data collection, and data analysis

Signal Processing and Classification

Hardware Improvement

March | April

Winter Break

November | December | January | February

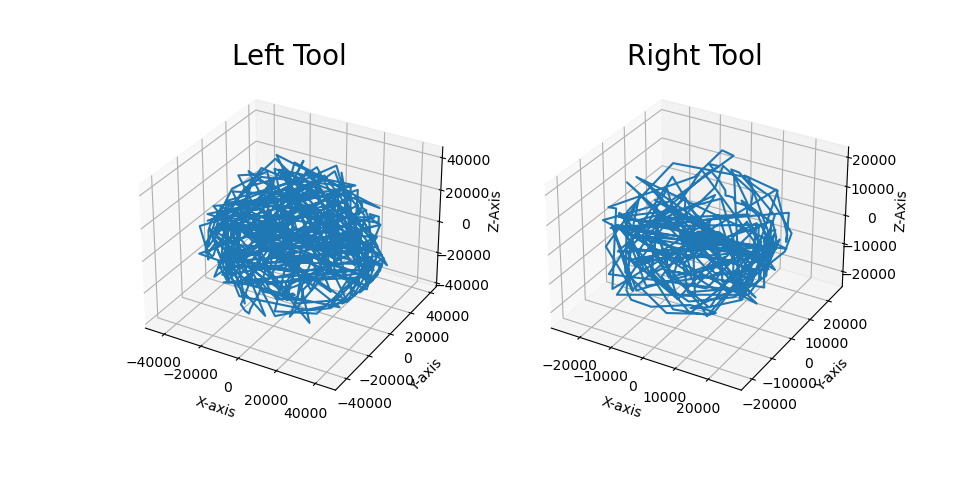
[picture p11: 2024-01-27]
Software/PresentationDemo/DemoFiles/ToolTrajectory.png

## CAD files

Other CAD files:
Hardware/CAD/Instrumented_Platform_B.f3d
Hardware/CAD/Instrumented_Platform_T.f3d
Hardware/CAD/circuit_housing.f3d
Hardware/CAD/trocar_mount.f3d

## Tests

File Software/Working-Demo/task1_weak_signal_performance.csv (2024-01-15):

 | Start Index | End Index | User Signal | Ref Signal | DTW Distance (Weak Performance)
0 | 0 | 83 | User_task1_L_pitchVel | Ref_task1_L_pitchVel | 5.747076551507631
1 | 0 | 83 | User_task1_L_x | Ref_task1_L_x | 3.1360557680096988
2 | 0 | 83 | User_task1_R_pitchAcc | Ref_task1_R_pitchAcc | 2.6336251578309455
3 | 0 | 83 | User_task1_R_pitchVel | Ref_task1_R_pitchVel | 4.306494628467766
4 | 0 | 83 | User_task1_R_yawVel | Ref_task1_R_yawVel | 5.090674509681033
5 | 83 | 166 | User_task1_L_yawVel | Ref_task1_L_yawVel | 4.716990566028302
6 | 166 | 249 | User_task1_L_yawVel | Ref_task1_L_yawVel | 6.128258770283407
7 | 166 | 249 | User_task1_L_roll | Ref_task1_L_roll | 2.7909242706535564
8 | 249 | 332 | User_task1_L_yawVel | Ref_task1_L_yawVel | 4.5
9 | 249 | 332 | User_task1_L_rollVel | Ref_task1_L_rollVel | 4.6097722286464435
10 | 249 | 332 | User_task1_L_roll | Ref_task1_L_roll | 4.205448522534929
11 | 332 | 415 | User_task1_L_yawVel | Ref_task1_L_yawVel | 4.663689526544408
12 | 332 | 415 | User_task1_L_rollVel | Ref_task1_L_rollVel | 4.527692569068709
13 | 332 | 415 | User_task1_L_motion | Ref_task1_L_motion | 2.7771023702830666
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

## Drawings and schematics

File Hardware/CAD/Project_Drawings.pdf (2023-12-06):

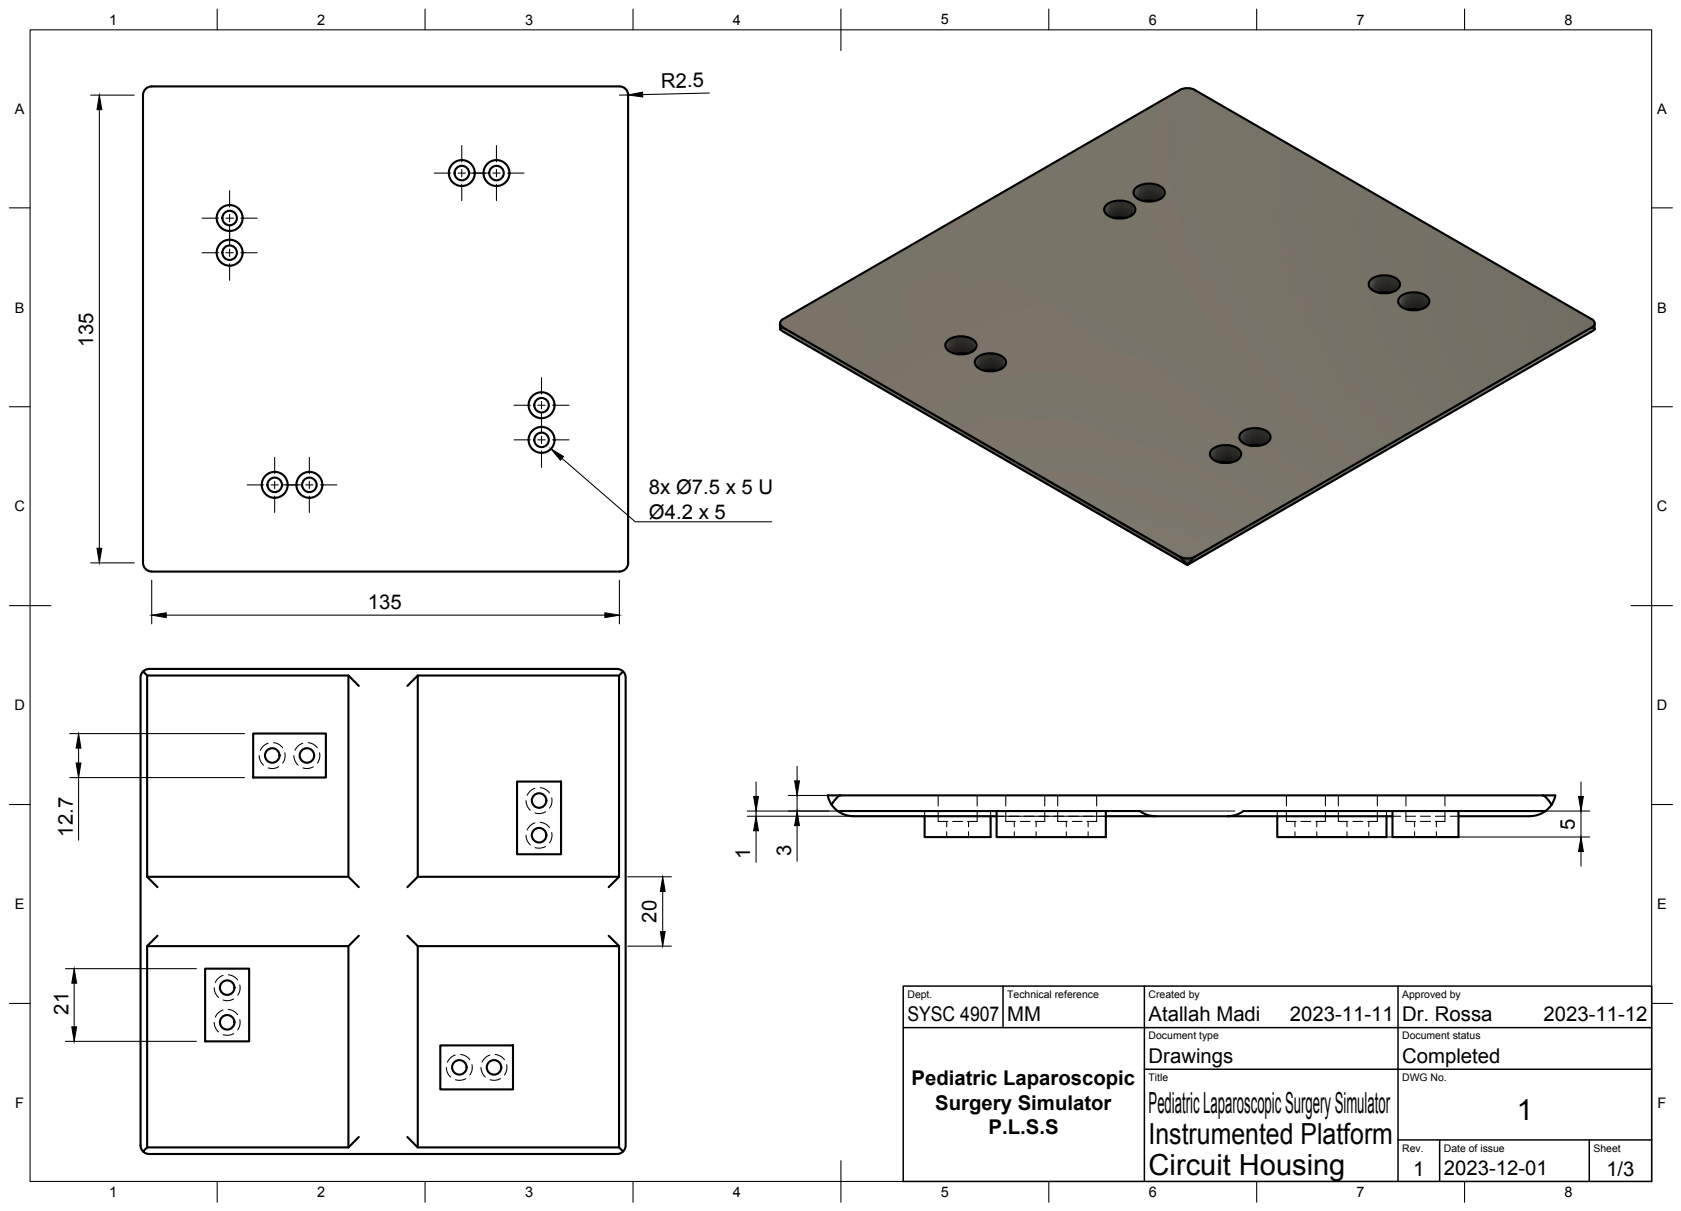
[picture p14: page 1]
Title; DWG No.; Rev.; Date of issue; Sheet; Circuit Housing; Instrumented Platform; Pediatric Laparoscopic Surgery Simulator

Dept. SYSC 4907 | Technical reference MM | Created by Atallah Madi 2023-11-11 | Approved by Dr. Rossa 2023-11-12

Document type Drawings | Document status Completed

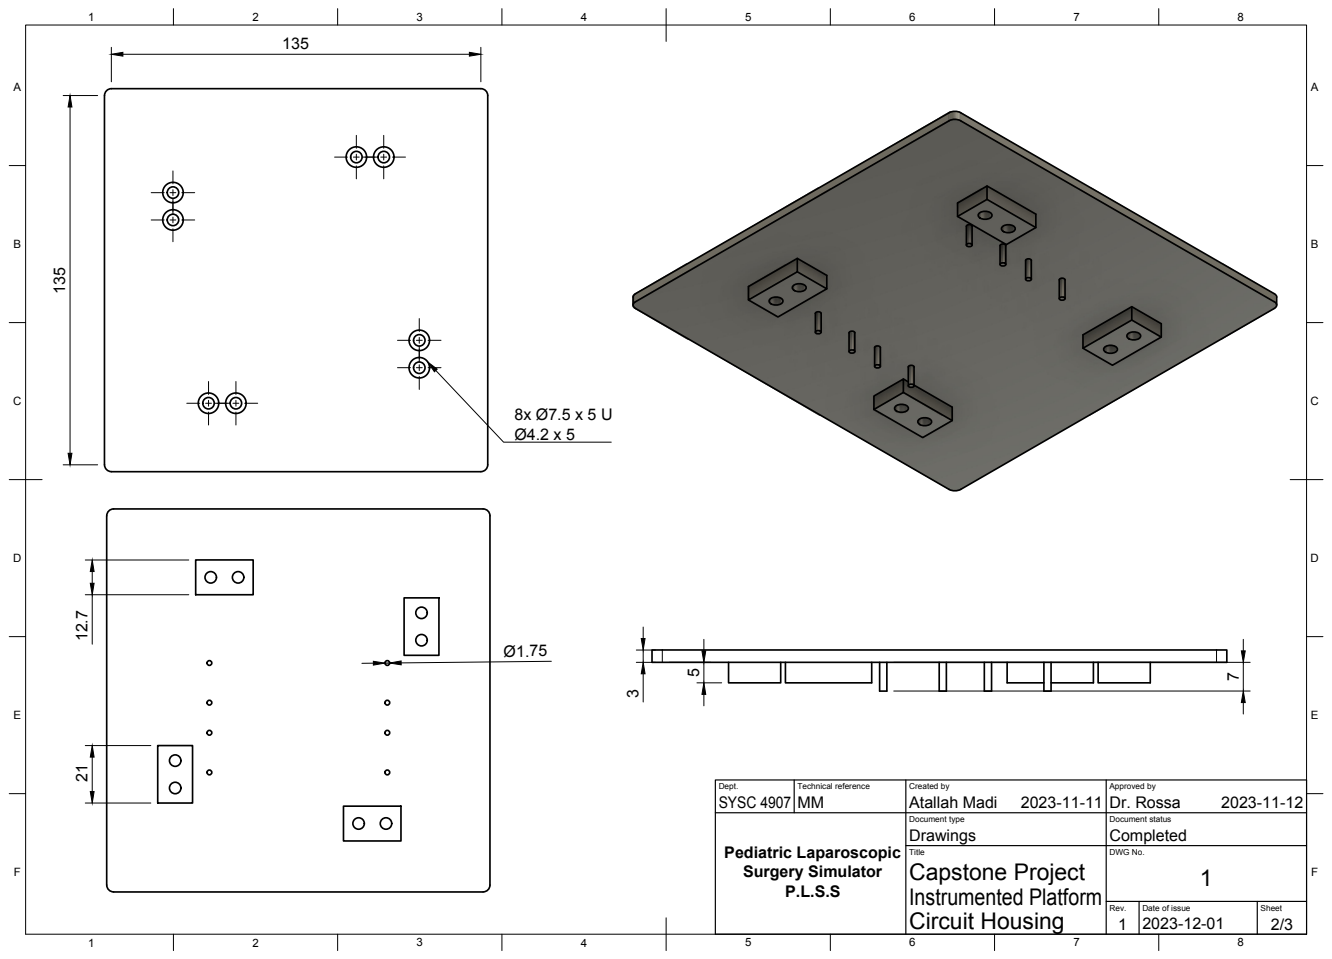
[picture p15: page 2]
Title; DWG No.; Circuit Housing; Capstone Project; SYSC 4907; Atallah Madi; Dr. Rossa 21 12.7 135; Pediatric Laparoscopic Surgery Simulator

Dept. | Technical reference | Created by 2023-11-11 | Approved by 2023-11-12

Document type Drawings | Document status Completed

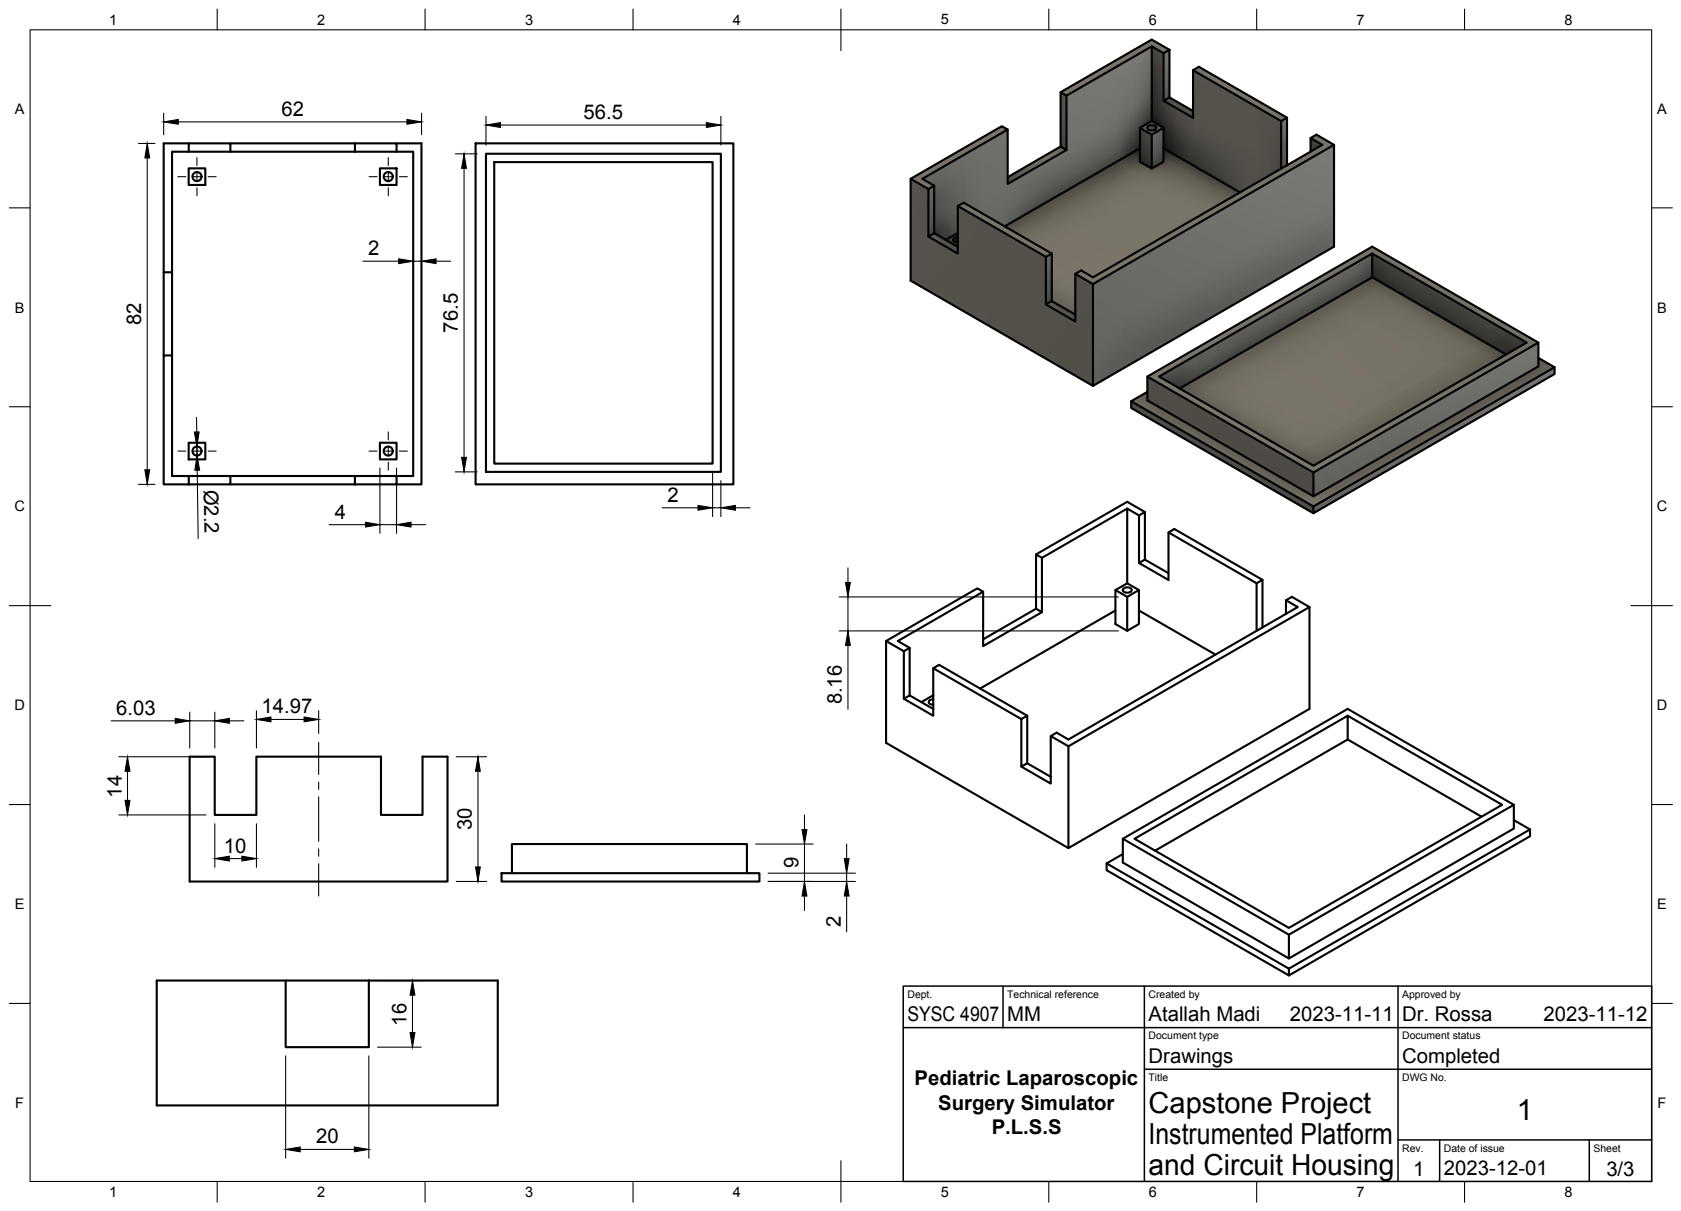
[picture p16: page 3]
Title; DWG No.; and Circuit Housing; Capstone Project; Pediatric Laparoscopic Surgery Simulator

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

Document type Drawings | Document status Completed

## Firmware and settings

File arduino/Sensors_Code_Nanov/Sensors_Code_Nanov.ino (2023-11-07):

/*********************************************************************************************
Author: Atallah Madi
Date: October 21th, 2023
Last edited: November 6th, 2023
Purpose: This code is used to read data from the MPU6050, PMW3389, and Force sensors.
The data is then sent to the computer via Serial. The data is then read by Python Application
This code is for the Arduino Nano.
*********************************************************************************************/

/* Libraries  */
// ---------------------------------------------------------------
#include <MPU6050_1.h> // Include the library for MPU6050 sensor
#include <MPU6050_2.h> // Include the library for MPU6050 sensor
#include <PMW3389.h>   // Include the library for PMW3389 sensor
#include <HX711.h>     // Include the HX711 library for force sensors
#include <Wire.h>      // Include the Wire library for I2C communication
#include <SPI.h>       // Include the SPI library for SPI communication
// ---------------------------------------------------------------

/* Initializing Libraries */
// ---------------------------------------------------------------
HX711 scale1;
HX711 scale2;
PMW3389 sensor1;          // LEFT HAND
PMW3389 sensor2;          // RIGHT HAND
MPU6050 mpu6050_1(Wire);  // LEFT HAND
MPU60502 mpu6050_2(Wire); // RIGHT HAND
// ---------------------------------------------------------------

/* Constants declaration, and pins declaration */
// ---------------------------------------------------------------
const int SERIAL_BAUD_RATE = 31250;

// SPI pins, digital pins
const int MISO_PIN = 12; // D12
const int MOSI_PIN = 11; // D11
const int SCK_PIN = 13;  // D13
const int SS_PIN_1 = 8;  // D8
const int SS_PIN_2 = 7;  // D7

// I2C pins, digital pins
const int SDA_PIN = 18; // A4
const int SCL_PIN = 19; // A5

// Force sensor pins, analog pins
const int DFORCE_CLK_PIN = 14;  // A0
const int DFORCE_DATA_PIN = 15; // A1
const int UFORCE_CLK_PIN = 16;  // A2
const int UFORCE_DATA_PIN = 17; // A3

const float SCALE_OFFSET = 136;         // this value is obtained by calibrating the scale with known weights
const float SCALE_FACTOR = 0.009806652; // Newtons = Grams * 0.009806652
// ---------------------------------------------------------------

/* Variables declaration */
// ---------------------------------------------------------------
long timer = millis();              // timer for MPU6050
long prevTimeSinceStart = millis(); // timer for PMW3389

// Sensor variables
float xL = 0;
float yL = 0;
float zL = 0;

float xR = 0;
float yR = 0;
float zR = 0;

float D_force = 0;
float U_force = 0;

float L_pitch = 0;
float L_yaw = 0;

float R_pitch = 0;
float R_yaw = 0;

float L_PMW_X = 0;
float L_PMW_X_vel = 0;
float L_PMW_X_acc = 0;
float L_PMW_Y = 0;
float L_PMW_Y_vel = 0;
float L_PMW_Y_acc = 0;

float R_PMW_X = 0;
float R_PMW_X_vel = 0;
float R_PMW_X_acc = 0;
float R_PMW_Y = 0;
float R_PMW_Y_vel = 0;
float R_PMW_Y_acc = 0;

float L_yawVel = 0;
float L_yawAcc = 0;
float L_pitchVel = 0;
float L_pitchAcc = 0;
float prev_L_yaw = 0;
float prev_L_yawVel = 0;
float prev_L_pitch = 0;
float prev_L_pitchVel = 0;

float R_yawVel = 0;
float R_yawAcc = 0;
float R_pitchVel = 0;
float R_pitchAcc = 0;
float prev_R_yaw = 0;
float prev_R_yawVel = 0;
float prev_R_pitch = 0;
float prev_R_pitchVel = 0;

float prev_L_PMW_X = 0;
float prev_L_PMW_Y = 0;
float prev_L_PMW_X_vel = 0;
float prev_L_PMW_Y_vel = 0;
float prev_R_PMW_X = 0;
float prev_R_PMW_Y = 0;
float prev_R_PMW_X_vel = 0;
float prev_R_PMW_Y_vel = 0;
// ---------------------------------------------------------------

/* Intializing Sensors */
// -------------------------------------------------------------
void setup()
{
  Wire.begin();
  Serial.begin(SERIAL_BAUD_RATE);

  // MPU portion
  mpu6050_1.begin();
  mpu6050_1.calcGyroOffsets(true);
  mpu6050_2.begin();
  mpu6050_2.calcGyroOffsets(true);

  while (!Serial)
    ; // Wait for serial to initialize.

  // PMW3389 portion
  /*
  NOT IN THE OLD CODE !!!
  SPI.begin();                  // Initialize SPI bus
  SPI.setDataMode(SPI_MODE0);   // CPOL = 0, CPHA = 0
  SPI.setBitOrder(MSBFIRST);    // MSB first
  SPI.setClockDivider(SPI_CLOCK_DIV16); // Adjust the clock divider as needed

  // Initialize the SS pins
  pinMode(SS_PIN_1, OUTPUT);    // Set SS pins as outputs
  pinMode(SS_PIN_2, OUTPUT);    // Set SS pins as outputs

  digitalWrite(SS_PIN_1, HIGH); // Set SS pins high initially
  digitalWrite(SS_PIN_2, HIGH); // Set SS pins high initially
  */

  sensor1.begin(SS_PIN_1, 16000); // to set CPI (Count per Inch), pass it as the
  sensor2.begin(SS_PIN_2, 16000); // second argument to the begin function

  // Force sensor portion
  scale1.begin(DFORCE_DATA_PIN, DFORCE_CLK_PIN);
  scale2.begin(UFORCE_DATA_PIN, UFORCE_CLK_PIN);

  scale1.set_scale(SCALE_OFFSET);
  scale2.set_scale(SCALE_OFFSET);

  scale1.tare();
  scale2.tare();
}

/* Main Program */
// -------------------------------------------------------------
void loop()
{
  unsigned long currentMillis = millis(); // current time for MPU6050 in milliseconds

  mpu6050_1.update(); // update MPU6050
  mpu6050_2.update(); // update MPU6050

  // Read data from sensors every 100 milliseconds
  if (currentMillis - timer > 100)
  {
    unsigned long timeSinceStart = millis();

    // MPU gets data from updates
    float L_yaw = mpu6050_2.getAngleY();
    float L_yawVel = 0;
    float L_yawAcc = 0;
    float L_pitch = mpu6050_2.getAngleX();
    float L_pitchVel = 0;
    float L_pitchAcc = 0;

    float R_yaw = mpu6050_1.getAngleY();
    float R_yawVel = 0;
    float R_yawAcc = 0;
    float R_pitch = mpu6050_1.getAngleX();
    float R_pitchVel = 0;
    float R_pitchAcc = 0;

    // Left MPU velocity and acceleration
    if (prev_L_yaw != 0)
    {
      L_yawVel = (L_yaw - prev_L_yaw) * 1000.00 / (timeSinceStart - prevTimeSinceStart); // deg/s
    }
    if (prev_L_pitch != 0)
    {
      L_pitchVel = (L_pitch - prev_L_pitch) * 1000.00 / (timeSinceStart - prevTimeSinceStart); // deg/s
    }

    // Accelerations
    if (prev_L_yawVel != 0)
    {
      L_yawAcc = (L_yawVel - prev_L_yawVel) * 1000.00 / (timeSinceStart - prevTimeSinceStart); // deg/s^2
    }
    if (prev_L_pitchVel != 0)
    {
      L_pitchAcc = (L_pitchVel - prev_L_pitchVel) * 1000.00 / (timeSinceStart - prevTimeSinceStart); // deg/s^2
    }

    // Right MPU velocity and acceleration
    if (prev_R_yaw != 0)
    {
      R_yawVel = (R_yaw - prev_R_yaw) * 1000.00 / (timeSinceStart - prevTimeSinceStart); // deg/s
    }
    if (prev_R_pitch != 0)
    {
      R_pitchVel = (R_pitch - prev_R_pitch) * 1000.00 / (timeSinceStart - prevTimeSinceStart); // deg/s
    }

    // Accelerations
    if (prev_R_yawVel != 0)
    {
      R_yawAcc = (R_yawVel - prev_R_yawVel) * 1000.00 / (timeSinceStart - prevTimeSinceStart); // deg/s^2
    }
    if (prev_R_pitchVel != 0)
    {
      R_pitchAcc = (R_pitchVel - prev_R_pitchVel) * 1000.00 / (timeSinceStart - prevTimeSinceStart); // deg/s^2
    }

    // Get data from PMW3389 sensors via readburst
    PMW3389_DATA data1 = sensor2.readBurst();
    PMW3389_DATA data2 = sensor1.readBurst();

    if (data1.isMotion || data1.isOnSurface)
    {
      L_PMW_X = ((data1.dx)) + L_PMW_X; // converts to 1mm since 16,000 CPI 16000=32767 in two's compliment so 32767=16,000=inch=25.4mm therefore 1290=1mmm.
      L_PMW_Y = ((data1.dy)) + L_PMW_Y; // Can measure 10cm on ruler and use that bit value to convert
    }
    if (data2.isMotion || data2.isOnSurface)
    {
      R_PMW_X = ((data2.dx)) + R_PMW_X; // converts to 1mm since 16,000 CPI 16000=32767 in two's compliment so 32767=16,000=inch=25.4mm therefore 1290=1mmm.
      R_PMW_Y = ((data2.dy)) + R_PMW_Y;
    }

    // Left PMW velocities
    if (prev_L_PMW_X != 0)
    {
      L_PMW_X_vel = (L_PMW_X - prev_L_PMW_X) / (timeSinceStart - prevTimeSinceStart); // units/s
    }
    if (prev_L_PMW_Y != 0)
    {
      L_PMW_Y_vel = (L_PMW_Y - prev_L_PMW_Y) / (timeSinceStart - prevTimeSinceStart); // units/s
    }

    // Left PMW accelerations
    if (prev_L_PMW_X_vel != 0)
    {
      L_PMW_X_acc = (L_PMW_X_vel - prev_L_PMW_X_vel) / (timeSinceStart - prevTimeSinceStart); // units/s^2
    }
    if (prev_L_PMW_Y_vel != 0)
    {
      L_PMW_Y_acc = (L_PMW_Y_vel - prev_L_PMW_Y_vel) / (timeSinceStart - prevTimeSinceStart); // units/s^2
    }

    // Right PMW velocities
    if (prev_R_PMW_X != 0)
    {
      R_PMW_X_vel = (R_PMW_X - prev_R_PMW_X) / (timeSinceStart - prevTimeSinceStart); // units/s
    }
    if (prev_R_PMW_Y != 0)
    {
      R_PMW_Y_vel = (R_PMW_Y - prev_R_PMW_Y) / (timeSinceStart - prevTimeSinceStart); // units/s
    }

    // Right PMW accelerations
    if (prev_R_PMW_X_vel != 0)
    {
      R_PMW_X_acc = (R_PMW_X_vel - prev_R_PMW_X_vel) / (timeSinceStart - prevTimeSinceStart); // units/s^2
    }
    if (prev_R_PMW_Y_vel != 0)
    {
      R_PMW_Y_acc = (R_PMW_Y_vel - prev_R_PMW_Y_vel) / (timeSinceStart - prevTimeSinceStart); // units/s^2
    }

    // If not in motion/on surface, reset acceleration value back to zero
    if (!(data1.isMotion || data1.isOnSurface))
    {
      L_PMW_X_acc = 0;
      L_PMW_Y_acc = 0;
      L_PMW_X_vel = 0;
      L_PMW_Y_vel = 0;
      L_PMW_X = 0;
      L_PMW_Y = 0;
    }
    if (!(data2.isMotion || data2.isOnSurface))
    {
      R_PMW_X_acc = 0;
      R_PMW_Y_acc = 0;
      R_PMW_X_vel = 0;
      R_PMW_Y_vel = 0;
      R_PMW_X = 0;
      R_PMW_Y = 0;
    }

    /* Force sensors readings */
    // -------------------------------------------------------------
    D_force = (scale1.get_units()) * SCALE_FACTOR;
    U_force = (scale2.get_units()) * SCALE_FACTOR;
    // -------------------------------------------------------------

    /* Pull additional data from MPU6050 */
    xL = mpu6050_1.getAccX();
    yL = mpu6050_1.getAccY();
    zL = mpu6050_1.getAccZ();

    xR = mpu6050_2.getAccX();
    yR = mpu6050_2.getAccY();
    zR = mpu6050_2.getAccZ();

    /*
    Print sensor data from Serial into .txt file
    D_force = Downwards force
    U_force = Upwards force
    L_PMW_Y / R_PMW_Y = surge
    L_PMW_X / R_PMW_X = roll
    L_pitch / R_pitch = pitch
    L_yaw / R_yaw = yaw
    */
    // -------------------------------------------------------------

    // OLD PRINT STATMENT !!!
    // Division by 1000.00 to convert pitch and yaw to smaller digit value
    // Serial.println(String(force) + "|" + String(L_pitchAcc / 1000.00) + "|" + String(L_yawAcc / 1000.00) + "|" + String(R_pitchAcc / 1000.00) + "|" +
    //                String(R_yawAcc / 1000.00) + "|" + String(L_PMW_Y_acc) + "|" + String(L_PMW_X_acc) + "|" + String(R_PMW_Y_acc) + "|" + String(R_PMW_X_acc) + '\n');

    // CURRENT PRINT STATMENT
    Serial.println(String(D_force) + "|" + String(U_force) + "|" +
                   String(L_pitchAcc / 1000) + "|" + String(L_yawAcc / 1000) + "|" +
                   String(R_pitchAcc / 1000) + "|" + String(R_yawAcc / 1000) + "|" +
                   String(L_PMW_Y_acc) + "|" + String(L_PMW_X_acc) + "|" +
                   String(R_PMW_Y_acc) + "|" + String(R_PMW_X_acc) + "|" +
                   String(L_pitchVel) + "|" + String(L_yawVel) + "|" +
                   String(R_pitchVel) + "|" + String(R_yawVel) + "|" +
                   String(L_PMW_Y_vel) + "|" + String(L_PMW_X_vel) + "|" +
                   String(R_PMW_Y_vel) + "|" + String(R_PMW_X_vel) + "|" +
                   String(L_pitch) + "|" + String(L_yaw) + "|" +
                   String(R_pitch) + "|" + String(R_yaw) + "|" +
                   String(L_PMW_Y) + "|" + String(L_PMW_X) + "|" +
                   String(R_PMW_Y) + "|" + String(R_PMW_X) + "|" +
                   String(xR) + "|" + String(yR) + "|" + String(zR) + "|" +
                   String(xL) + "|" + String(yL) + "|" + String(zL) + "|" +
                   String(data1.isMotion && data1.isOnSurface) + "|" +
                   String(data2.isMotion && data2.isOnSurface));

    /* Save previous values */
    // -------------------------------------------------------------
    prevTimeSinceStart = timeSinceStart;
    prev_L_yaw = L_yaw;
    prev_L_yawVel = L_yawVel;
    prev_L_pitch = L_pitch;
    prev_L_pitchVel = L_pitchVel;

    prev_R_yaw = R_yaw;
    prev_R_yawVel = R_yawVel;
    prev_R_pitch = R_pitch;
    prev_R_pitchVel = R_pitchVel;

    prev_L_PMW_X = L_PMW_X;
    prev_L_PMW_X_vel = L_PMW_X_vel;
    prev_L_PMW_Y = L_PMW_Y;
    prev_L_PMW_Y_vel = L_PMW_Y_vel;

    prev_R_PMW_X = R_PMW_X;
    prev_R_PMW_X_vel = R_PMW_X_vel;
    prev_R_PMW_Y = R_PMW_Y;
    prev_R_PMW_Y_vel = R_PMW_Y_vel;
  }
}

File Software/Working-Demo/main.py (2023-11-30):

import tkinter as tk
from tkinter import messagebox, filedialog, Toplevel

import cv2
import imageio
from PIL import Image, ImageTk
import pandas as pd
import os
import numpy as np
import time
import serial
import threading
#import matplotlib.pyplot as plt
#from matplotlib.widgets import Slider, CheckButtons
from cleaning_sensor_data import SensorDataCleaner
from seg_data_to_subtasks import DataSegmentation
from user_task1_evaluation import Task1PerformanceAnalyzer
from plot_user_aligned_subtasks import DataPlotter
from show_feedback_video import VideoPlayer
from itertools import cycle


class Application(tk.Tk):
    def __init__(self):
        super().__init__()
        self.title('Video Application')

        # Get the screen width and height
        self.screen_width = self.winfo_screenwidth()
        self.screen_height = self.winfo_screenheight()

        # Set the window size to the maximum screen size
        self.geometry(f'{self.screen_width}x{self.screen_height}')
        self.resizable(False, False)
        self.configure(bg='black')
        self.video_name = "LapSim1.mkv"
        self.video = imageio.get_reader(self.video_name)
        self.canvas = tk.Canvas(self, width=self.screen_width, height=self.screen_height)
        self.bind('<ButtonPress-1>', self.mouse_down)
        self.bind('<ButtonRelease-1>', self.mouse_up)
        self.bind('<B1-Motion>', self.mouse_drag)
        # First, create the shadow with an offset (e.g., 2 pixels to the right and down)
        self.shadow_offset_x = 3
        self.shadow_offset_y = 3
        self.shadow_color = 'black'
        self.welcome_text = self.canvas.create_text(self.screen_width/2, self.screen_height/3 + 50, text='Welcome', font=('MS Sans Serif', 100), fill='black', tags=("overlay", "text",))
        #self.welcome_shadow = self.canvas.create_text(self.screen_width/2 + self.shadow_offset_x, self.screen_height/3 + self.shadow_offset_y,text="Welcome",font=('MS Sans Serif', 100), fill=self.shadow_color, tags=("shadow",))
        #self.rect = self.canvas.create_rectangle(self.screen_width/2 + 400, 700, self.screen_height/3 + 100, 100, fill="black")
        self.current_user = None
        self.back_button = None
        self.buttons = []
        self.base_directory = 'C:/Users/hudaa/PycharmProjects/pythonProject1/UserData'
        # Initialize the cycle of images
        self.image_paths = ["Slide2.png", "Slide3.png", "Slide4.png", "Slide5.png", "Slide6.png", "Slide7.png", "Slide8.png", "Slide9.png"]
        self.load_video()
        self.start_menu()
        self.canvas.pack()


    def create_user_folder(self, username):
        # Sanitize the username to prevent any invalid characters for folder names
        # This is important for security and compatibility of folder names
        safe_username = ''.join(c for c in username if c.isalnum() or c in (' ', '_')).rstrip()

        # Create the full path for the user's folder
        user_folder_path = os.path.join(self.base_directory, safe_username)

        # Check if the folder already exists, and if not, create it
        if not os.path.exists(user_folder_path):
            os.makedirs(user_folder_path)
            print(f"Folder created for user {safe_username} at {user_folder_path}")
        else:
            print(f"Folder already exists for user {safe_username} at {user_folder_path}")

        return user_folder_path
    def set_current_user(self, username):
        self.current_user = username
        #user_folder = self.create_user_folder(self.base_directory, self.current_user)

    def mouse_down(self, event):
        self.x, self.y = event.x, event.y

    def mouse_up(self, event):
        self.x, self.y = None, None

    def mouse_drag(self, event):
        if self.x and self.y:
            deltax = event.x - self.x
            deltay = event.y - self.y
            x0 = self.winfo_x() + deltax
            y0 = self.winfo_y() + deltay
            self.geometry(f"+{x0}+{y0}")

    def load_video(self):
        self.after(0, self.stream())

    def update_frame(self, frame_iterator):
        try:
            image = next(frame_iterator)
            resized_image = Image.fromarray(image).resize((self.winfo_screenwidth(), self.winfo_screenheight()),Image.Resampling.LANCZOS)  # Use the screen dimensions
            frame_image = ImageTk.PhotoImage(image=resized_image)
            if hasattr(self, 'canvas_image_id'):
                # Update the existing image object
                self.canvas.itemconfig(self.canvas_image_id, image=frame_image)
            else:
                # Create a new canvas image object and keep its ID
                self.canvas_image_id = self.canvas.create_image(
                    0, 0, anchor='nw', image=frame_image, tags=("video_frame",)
                )
                # Send this image to the back, so buttons/text stay on top
                self.canvas.tag_lower('video_frame')

            # Keep a reference to the image to prevent garbage-collection
            self.canvas.image = frame_image

            # Send this image to the back, so buttons/text stay on top
            self.canvas.tag_lower('video_frame')
            self.canvas.tag_raise('overlay')
            self.canvas.update_idletasks()

            # Schedule the next frame update
            self.after(33, self.update_frame, frame_iterator)  # For ~30fps, adjust as needed
        except StopIteration:
            # Handle the end of the video stream
            self.canvas.delete(self.canvas_image_id)  # Remove the video frame
            self.start_menu()  # Call start_menu or handle the video ending

    def stream(self):
        frame_iterator = iter(self.video.iter_data())
        self.update_frame(frame_iterator)

        #self.canvas.create_text(self.screen_width/3 + 20 + self.shadow_offset_x, (self.screen_height/4 - 20) + self.shadow_offset_y,text="Pediatric Laparoscopic Surgical Simulator",font=('Helvetica', 16), fill=self.shadow_color, tags=("shadow",))
        self.canvas.create_text(
            self.screen_width/3 + 20, self.screen_height/4 - 20,
            text="Pediatric Laparoscopic Surgical Simulator",
            font=('MS Sans Serif', 20), fill='black', tags=("overlay",)
        )

        if (self.current_user != None):
            self.canvas.create_text(
                800, 300,
                text="Welcome "+str(self.current_user),
                font=('MS Sans Serif', 18), fill='white', tags=("overlay",)
            )

    def raise_buttons_and_text(self):
        # Assuming all your buttons and text have a common tag like "overlay"
        self.canvas.tag_raise("overlay")
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

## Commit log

2023-09-19 First PUSH
    [Circuit_Housing.f3d, Circuit_Housing.stl, Prototype_To_Arduino.dwg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]
2023-09-23 organizing by atallah.
    [Circuit_Housing.f3d, Circuit_Housing.stl, Prototype_To_Arduino.dwg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]
2023-09-26 Cleaning Sensor Data EXE File Added
2023-11-10 onedrive org
    [amplifier_placement.f3d, circuit_housing.f3d, force_plate_bottom.f3d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]
2023-11-11 Final arduino code
2023-11-22 add new CAD and software files
    [Instrumented_Platform_B.f3d, Instrumented_Platform_T.f3d, amplifier_placement.f3d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]
2023-11-29 Files needed to run my scripts for now
    [CleanedSensorData_2.csv, CleanedSensorData_6.csv, Labelled Videos.xlsx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]
2023-11-30 for video buttons
2023-12-06 added prog report, cad dwg, and py uml
